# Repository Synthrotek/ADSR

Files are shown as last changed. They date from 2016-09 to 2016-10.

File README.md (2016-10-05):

# ADSR

##Important Information

The ADSR is Open Hardware, all hardware and software design in that project is Creative Commons licensed by Steve Harmon: CC-BY-SA: Attribution / ShareAlike.

##Information for re-use, adaptations or derivative works

Synthrotek is trademarked, and should not be used on any of works you create from these files.

We ask that if you want to re-use all or part of the files provided on github that you change the name of the product to something else, and remove any Synthrotek logos or names. Please do not contact Synthrotek for any support on the derivitive works. We can not be held liable for any derivitive works.

##About the ADSR

The Synthrotek ADSR is a small and simple envelope generator with some very useful features.  CV is additive for overall length of ADR stages in ADSR mode and add even more length to just the Release stage by adding CV into the Release jack. AR mode allows for snappy to long dynamic rhythm lengths. Very short minimum lengths, self cycling and a maximum output of 5 volts makes this tiny (4HP) envelope a very feature packed and versatile module.

Stage Lengths:
Attack: 4ms-2 seconds (up to ~ 4 seconds with CV)
Decay: 4ms-2 seconds (up to ~ 4 seconds with CV)
Sustain (based on gate length)
Release 4ms-2 seconds (up to ~ 4 seconds with CV)

Depth: 40mm
HP: 4
Current Draw: +12: 30mA, -12: n/a, +5: n/a

The source code was compiled using atmel studio 6.1

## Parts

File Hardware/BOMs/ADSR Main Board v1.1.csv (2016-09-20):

RefDes | Name | Value | Quantity | Vendor | Vendor Part No.
C1 | Cap Ceramic Radial - 18pF | 18pF | 1 | Mouser | 581-SR152A180JAA
C2 | Cap Ceramic Radial - 18pF | 18pF | 1 | Mouser | 581-SR152A180JAA
C3 | Cap Electrolytic Radial - 22uF | 22uF 25V | 1 | Mouser | 647-UVZ1E220MDD1TD 647-UVZ1E220MDD1TD 647-UVZ1E220MDD1TD
C4 | Cap Ceramic Radial - .1uF | .1uF | 1 | Mouser | 80-C316C104M5UCA7301
C5 | Cap Ceramic Radial - .1uF | .1uF | 1 | Mouser | 80-C316C104M5UCA7301
D1 | BAT85 |  | 1
D2 | BAT85 |  | 1
D3 | BAT85 |  | 1
D4 | BAT85 |  | 1
D5 | BAT85 |  | 1
D6 | BAT85 |  | 1
D7 | BAT85 |  | 1
P1 | Header RA - 10P (2x5) Protruding Left |  | 1 | Mouser | 538-10-89-4102
P2 | Header RA - 10P (2x5) Protruding Left |  | 1 | Mouser | 538-10-89-4102
P4 | Header 4-Wall - 10 Pin |  | 1 | Mouser | 517-30310-6002
R1 | Resistor - 1/4 Watt | 2K | 1
R2 | Resistor - 1/4 Watt | 1K | 1
R3 | Resistor - 1/4 Watt | 100K | 1
R4 | Resistor - 1/4 Watt | 100K | 1
R5 | Resistor - 1/4 Watt | 20K | 1
R6 | Resistor - 1/4 Watt | 1K | 1
R7 | Resistor - 1/4 Watt | 2K | 1
R8 | Resistor - 1/4 Watt | 1K | 1
R9 | Resistor - 1/4 Watt | 2K | 1
R10 | Resistor - 1/4 Watt | 100K | 1
R11 | Resistor - 1/4 Watt | 1R0 | 1
R12 | Resistor - 1/4 Watt | 2K | 1
R13 | Resistor - 1/4 Watt | 1K | 1
R14 | Resistor - 1/4 Watt | 1K | 1
U1 | ATMEGA48_PDIP |  | 1 | Mouser | 556-ATMEGA88A-PU
U2 | 74LS14N |  | 1
U3 | MCP4921 | DAC | 1 | Mouser | 579-MCP4921-E/P
VR1 | 78L05 |  | 1 | Mouser | 512-MC78L05ACP
X1 | Crystal - 20MHZ | 20MHZ | 1 | Mouser | 815-ABL-20-B2

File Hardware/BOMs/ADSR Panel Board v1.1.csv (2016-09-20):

# | RefDes | Name | Value | Quantity | Vendor | Vendor Part No.
1 | J1 | 3.5mm Jack WQP-PJ301M-12 2HP |  | 1 | WQP | WQP-PJ301M-12
2 | J2 | 3.5mm Jack WQP-PJ301M-12 2HP |  | 1 | WQP | WQP-PJ301M-12
3 | J3 | 3.5mm Jack WQP-PJ301M-12 2HP |  | 1 | WQP | WQP-PJ301M-12
4 | J4 | 3.5mm Jack WQP-PJ301M-12 2HP |  | 1 | WQP | WQP-PJ301M-12
7 | R1 | Bourns Lighted Slide Pot PTL Series | 10k | 1 | Mouser | 652-PTL20-10O0-103B2
8 | R2 | Bourns Lighted Slide Pot PTL Series | 10k | 1 | Mouser | 652-PTL20-10O0-103B2
9 | R3 | Bourns Lighted Slide Pot PTL Series | 10k | 1 | Mouser | 652-PTL20-10O0-103B2
10 | R4 | Bourns Lighted Slide Pot PTL Series | 10k | 1 | Mouser | 652-PTL20-10O0-103B2
11 | SW1 | LED-Switch SM102 ON-ON |  | 1 | LED-Switch | SM103
12 | SW2 | LED-Switch SM102 ON-ON |  | 1 | LED-Switch | SM103

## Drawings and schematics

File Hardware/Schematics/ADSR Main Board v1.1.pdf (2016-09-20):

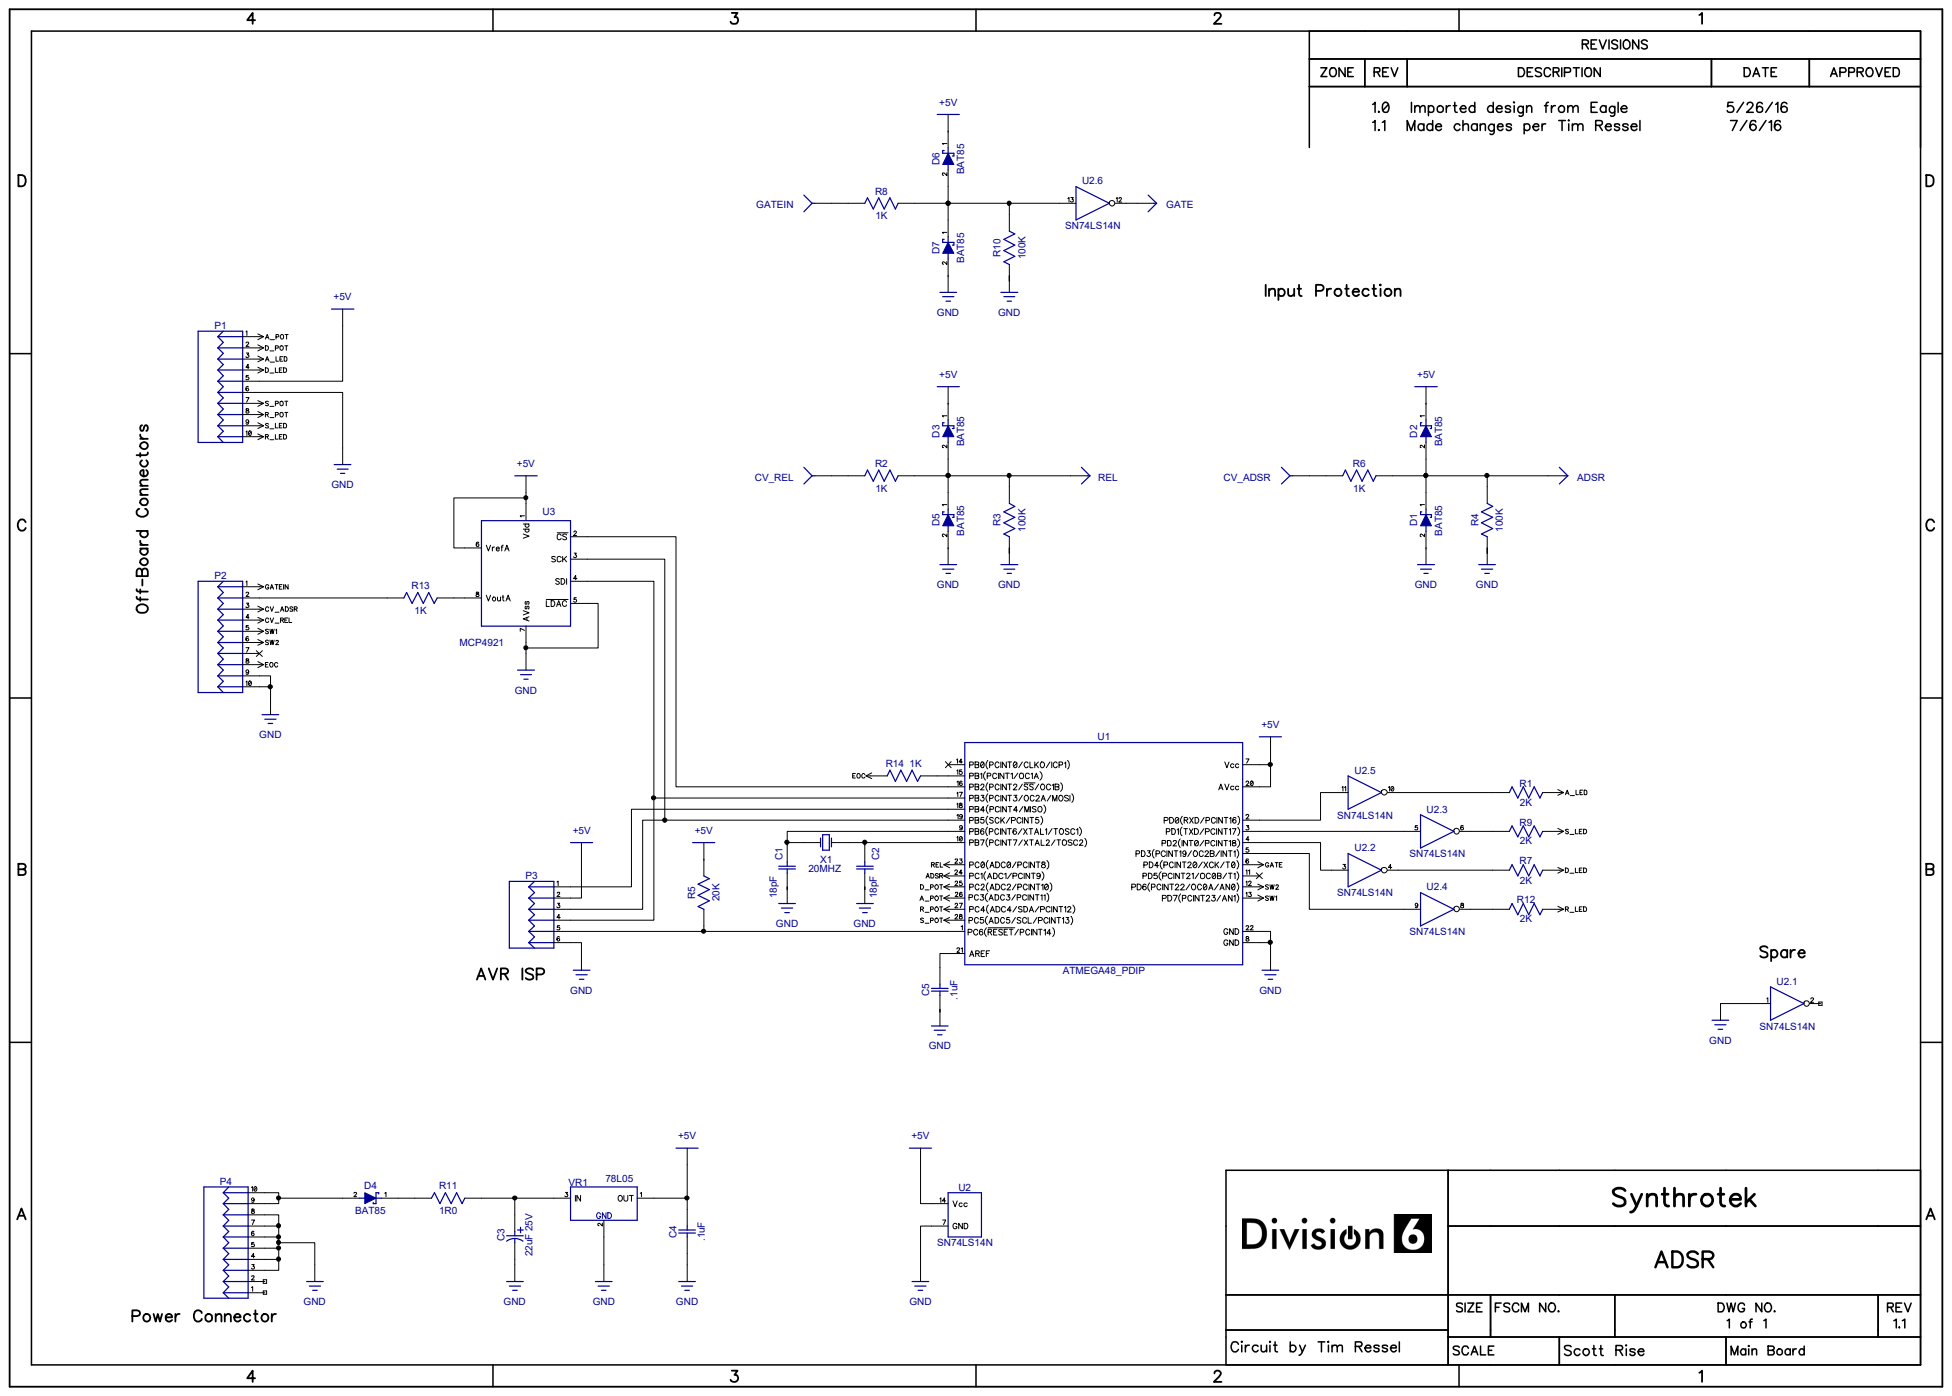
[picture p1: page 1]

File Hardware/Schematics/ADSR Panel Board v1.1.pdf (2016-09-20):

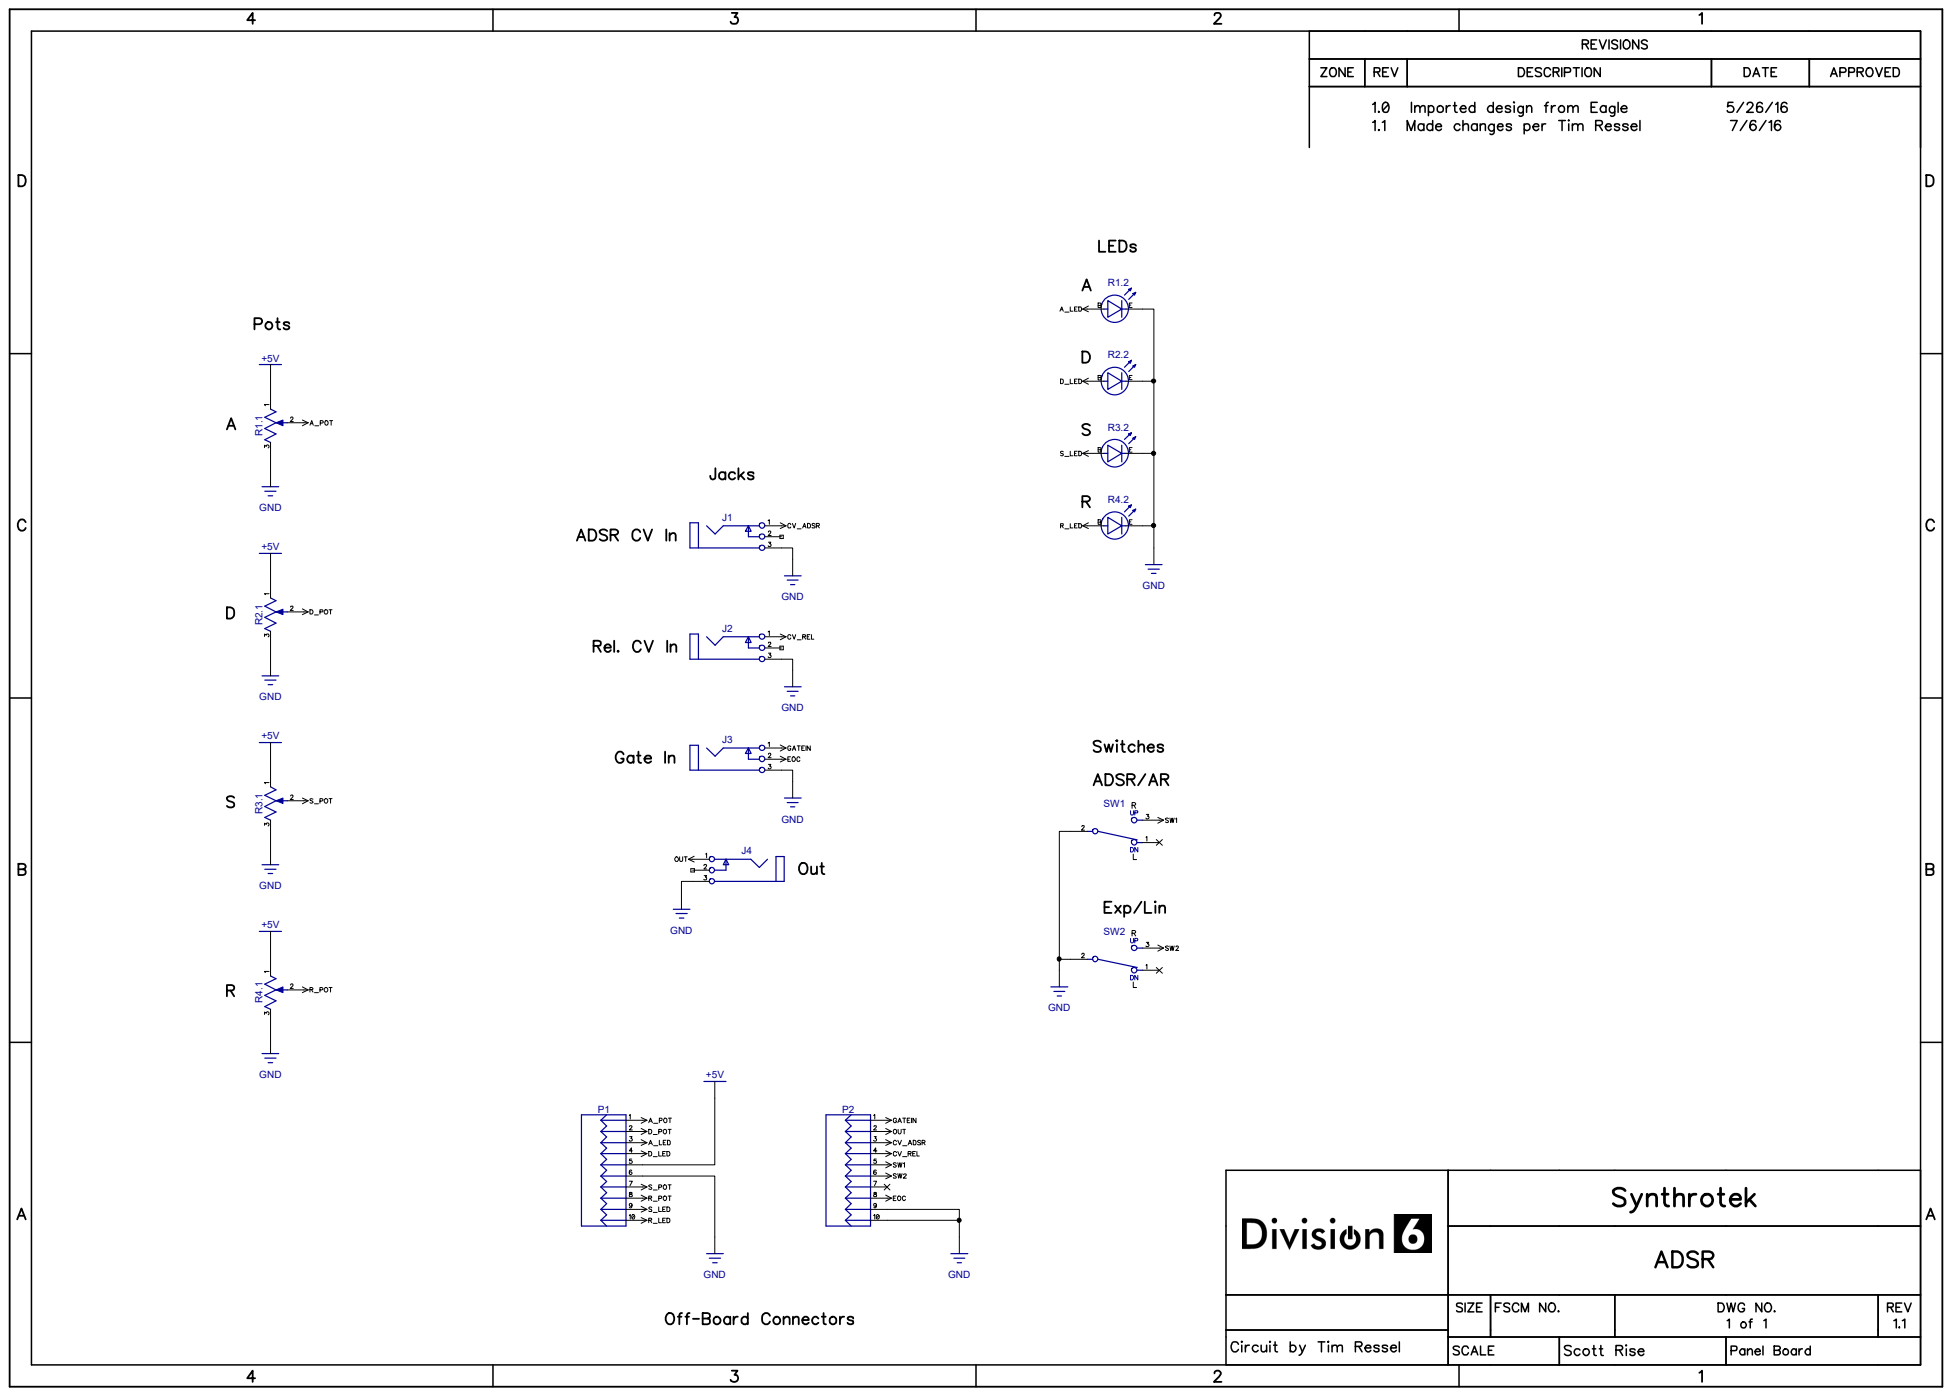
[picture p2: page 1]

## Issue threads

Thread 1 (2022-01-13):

eagle / cad files availability?

KeLaiFu, 2022-01-13:
I'f like to build this module but at the moment the slider used isnt available in my country and I would need to import it. Would it be possible to get the eagle / kicad file so I could switch the footprint for something more accessable?

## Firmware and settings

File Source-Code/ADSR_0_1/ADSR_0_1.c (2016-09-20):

/*
* ADSR_0_1.c
*
* Created: 6/28/2016 1:45:45 PM
*  Author: TimR
*/

#include "stdio.h"
#include "stdlib.h"
#include "string.h"
#include "avr/io.h"
#include "avr/interrupt.h"

// Prototypes
void process_adsr(void);
void	init_ports(void);
void	init_devices(void);
void	pgm_init(void);
void	timer_init(void);
void SendToShiftyTypes(void);


// Hardware Defines
#define LEDS_ATTACK		0x01
#define LEDS_DECAY		0x04
#define LEDS_SUSTAIN	0x02
#define LEDS_RELEASE	0x08
#define LEDS_IDLE_MASK	0xF0

#define SW_AR		PIND&0x80		// 0=AR, 1=ADSR
#define SW_LIN		PIND&0x40		// 0=lin, 1=expo

#define	EOC_HI		PORTB|=0x02;
#define	EOC_LO		PORTB&=~0x02;

// Shifty Types
#define	SS_LO		PORTB&=~0x04;
#define	SS_HI		PORTB|=0x04;

// LED macros
#define LED_ATTACK	{PORTD|=~LEDS_IDLE_MASK;PORTD&=~LEDS_ATTACK;}
#define LED_DECAY	{PORTD|=~LEDS_IDLE_MASK;PORTD&=~LEDS_DECAY;}
#define LED_SUSTAIN	{PORTD|=~LEDS_IDLE_MASK;PORTD&=~LEDS_SUSTAIN;}
#define LED_RELEASE	{PORTD|=~LEDS_IDLE_MASK;PORTD&=~LEDS_RELEASE;}
#define LED_IDLE	{PORTD|=~LEDS_IDLE_MASK;}

//#define	EXPOEPSILON		0x01FFFFFF
#define	EXPOEPSILON		0x0000FFFF
#define ADCCHANNELMAX	6
#define	EOC_TIMEOUT		9			// about ?mS

// Globals

enum states {
	s_idle,
	s_att,
	s_dec,
	s_sus,
	s_rel
};

struct adsr {
	uint32_t	attack;
	uint32_t	decay;
	uint32_t	sustain;
	uint32_t	release;
	uint32_t	accum;
	uint32_t	curDac;
	uint8_t		state;
};
volatile struct adsr thisADSR;

volatile	uint16_t	rawAdcPots[4];	// raw pot values from ADC
volatile	uint16_t	rawAdcSum[4];	// sum of raw pot values and adsr/rel values
uint16_t	rel_cv,adsr_cv;				// raw ADC values from rel and adsr jacks
uint8_t		flgShape;					//sets lin or expo shape, 
uint8_t		flgAR,flgARold;				//sets AR mode -- from FP switch
volatile uint8_t	flgGate;			// set when a rising Gate is detected
uint8_t		thisAdcChannel;				// current ADC mux setting
uint8_t		flgProcess;					// shows its time to process the ADSR
volatile uint8_t		flgEOC,tmrEOC;

int main(void)
{
	cli();
	init_ports();
	init_devices();
	timer_init();
	pgm_init();
	sei();
	
	ADCSRA |= (1<<ADIE);					// enable ADC interrupts
	ADCSRA |= (1<<ADSC);				//start next conversion

	while(1)
	{
		// wait for gate flag
		if(flgGate)
		{
			flgGate=0;			// clear flag
			LED_ATTACK
			thisADSR.state = s_att;
		}
		// wait for processing flag
		// decouples from the irq so the processing does not happen
		// inside an irq.
		if(flgProcess)
		{
			flgProcess=0;			// clear flag
			// set env based on switch
			if(SW_AR)
				flgAR=0;		// adsr
			else
				flgAR=1;		//ar
			if(flgARold!=flgAR)
				thisADSR.state = s_att;
			flgARold=flgAR;
			
			// set shape based on switch
			if(SW_LIN)
				flgShape=0;		// expo
			else
				flgShape=1;		// lin			
			process_adsr();
			SendToShiftyTypes();
		}
	}
}


void	init_ports(void)
{
	DDRB = 0x2E;
	DDRC = 0x00;		// all inputs of the ADC variety
	PORTD = 0xC0;		// pull ups on PD6 & 7
	DDRD = 0x0F;		//PD0-3 outputs, rest inputs
}


void process_adsr(void)
{
	static uint32_t		NextExpoAmt;
	//	static uint8_t		flgRetrigOld;
	//	uint16_t			index;
	cli();
	
	switch (thisADSR.state) {
		case s_idle:
		break;
		
		case s_att:
		if(flgShape) {
			//linear processing
			if((int64_t)(0x7fffffff-(thisADSR.accum)) < (thisADSR.attack)) {
				thisADSR.accum=0x7fffffff;
				if(flgAR) {
					thisADSR.state=s_rel;
					LED_RELEASE
				} else {
					thisADSR.state=s_dec;
					LED_DECAY
				}
			}
			else
			thisADSR.accum+=((thisADSR.attack)/2);
			thisADSR.curDac=thisADSR.accum*2;
		}
		else {
			//expo processing
			NextExpoAmt=(0x9fffffff-thisADSR.accum);
			NextExpoAmt=NextExpoAmt/((rawAdcSum[0]*2)+8);
			NextExpoAmt=NextExpoAmt*3;
			NextExpoAmt=NextExpoAmt/4;
			
			if(NextExpoAmt>0x7ffffff0)
			NextExpoAmt=0x7ffffff0;
			if(NextExpoAmt<0)
			NextExpoAmt=0x7ffffff0;
			if((0x7fffffff-(thisADSR.accum)) <= NextExpoAmt+EXPOEPSILON) {
				thisADSR.accum=0x7fffffff;
				if(flgAR) {
					thisADSR.state=s_rel;
					LED_RELEASE
					} else {
					thisADSR.state=s_dec;
					LED_DECAY
				}
			}
			else
			thisADSR.accum+=NextExpoAmt;
			thisADSR.curDac=thisADSR.accum*2;
		}
		
		break;
		
		case s_dec:
		if(flgShape) {
			//linear processing
			if(((int64_t)thisADSR.accum - (int64_t)(thisADSR.decay)) < thisADSR.sustain/2) {
				thisADSR.accum=thisADSR.sustain/2;
				thisADSR.state=s_sus;
				LED_SUSTAIN
			}
			else
			thisADSR.accum-=(thisADSR.decay/2);
			
			thisADSR.curDac=thisADSR.accum*2;
			//break;
			
			} else {
			//expo processing
			NextExpoAmt=(thisADSR.accum-(thisADSR.sustain/2));
			NextExpoAmt=NextExpoAmt/((rawAdcSum[1]*3)+12);
			NextExpoAmt=((NextExpoAmt*12)/10);
			NextExpoAmt=NextExpoAmt;

			if((int64_t)thisADSR.accum-((thisADSR.sustain/2)+EXPOEPSILON)<NextExpoAmt) {
				thisADSR.accum-=NextExpoAmt*2;
				thisADSR.state=s_sus;
				LED_SUSTAIN
			}
			else
			thisADSR.accum-=NextExpoAmt*2;
			thisADSR.curDac=thisADSR.accum*2;
		}

		break;
		
		case s_sus:
		thisADSR.accum=thisADSR.sustain/2;
		thisADSR.curDac=thisADSR.accum*2;
		//if(PORTA.IN & PIN6_bm)
		if((PIND & 0x10)==0x10)	{					// is Gate went away i.e. high (inverted)
			thisADSR.state=s_rel;						// jump to release state
			LED_RELEASE
		}
		break;

		case s_rel:
		if(flgShape) {
			//linear processing
			if(thisADSR.accum <= (thisADSR.release)) {
				thisADSR.accum=0;
				thisADSR.state=s_idle;
				LED_IDLE
				
				// use for cycle mode...
				EOC_HI;
				tmrEOC=0;
				flgEOC=1;
				
			}
			else
			thisADSR.accum-=((thisADSR.release)/2);
			
			//process exp curve crap
			thisADSR.curDac=thisADSR.accum*2;
			} else {
			//process exp curve
			NextExpoAmt=thisADSR.accum;
			NextExpoAmt=NextExpoAmt/((rawAdcSum[3]*3)+12);
			NextExpoAmt=((NextExpoAmt*3)/2);
			NextExpoAmt=NextExpoAmt;

			//if(thisADSR.accum <= EXPOEPSILON) {
			if((int32_t)thisADSR.accum<(NextExpoAmt+EXPOEPSILON)) {
				thisADSR.accum=0;
				thisADSR.state=s_idle;
				LED_IDLE
				// use for cycle mode...
				EOC_HI;
				tmrEOC=0;
				flgEOC=1;

			}
			
			else
			thisADSR.accum-=((NextExpoAmt/8)*18);
			thisADSR.curDac=thisADSR.accum*2;
			break;
		}
	}
	sei();
}


void init_devices(void)
{
	//
	// sets up ADC system
	//
	ADMUX = (1<<REFS0);		//AVCC as reference
	ADCSRA = (1<<ADPS2)|(1<<ADPS1)|(1<<ADPS0)|(1<<ADEN);

	//
	// enable IRQ on Gate jack input
	PCMSK2 = (1<<PCINT20);		
	PCICR = (1<<PCIE2);						//enable interrupts
	
	// ***SPI***
	SPCR = (1<<SPE)|(1<<MSTR)|(1<<SPR0);	// SPI enable	
}


void pgm_init(void)
{
	// setup mux channel
	thisAdcChannel=0;
	ADMUX |= thisAdcChannel;
	LED_IDLE
	SS_HI;
}


void adcProcess(void)
{
	rawAdcSum[0]=rawAdcPots[0]+adsr_cv;
	rawAdcSum[1]=rawAdcPots[1]+adsr_cv;
	rawAdcSum[2]=rawAdcPots[2];
	rawAdcSum[3]=rawAdcPots[3]+adsr_cv+rel_cv;
	
	thisADSR.attack=0x20000000/((rawAdcSum[0]+0x02)/0x02);
	thisADSR.decay=0x20000000/((rawAdcSum[1]+0x02)/0x02);
	thisADSR.sustain=(uint32_t)rawAdcSum[2]<<22;
	thisADSR.release=0x20000000/((rawAdcSum[3]+0x02)/0x02);
}


void SendToShiftyTypes(void)
{
	uint8_t		dummy;
	uint16_t	sendVal;

	cli();
	SS_LO;
	
	sendVal = thisADSR.curDac>>20;
	sendVal = sendVal | 0x3000;			//gain=1,active mode
	
	SPDR=sendVal>>8;					// send MSB
	do {} while (!(SPSR&(1<<SPIF)));
	dummy=SPDR; 				//dummy read to clear flag

	SPDR=sendVal&0x00FF;				// send LSB
	do {} while (!(SPSR&(1<<SPIF)));
	dummy=SPDR; 				//dummy read to clear flag
	
	SS_HI;
	sei();
}

void timer_init(void)
{
	// for 20.0000MHz clock
	// timer 0 is the 1mS (0.5mS?) tick
	TCCR0A  = (1<<WGM01);					// ctc mode
	TCCR0B  = (1<<CS02); 					// divide by 256
	OCR0A   = 0x26;							// or 38 decimal -- 0.5mS
	TIMSK0	= 1<<OCIE0A;					// output compare A match irq
}


//	ADC interrupt
ISR(ADC_vect)
{
	//process results
	switch (thisAdcChannel) {
		case 0:
		rel_cv = ADC;
		break;
		case 1:
		adsr_cv = ADC;
		break;
		case 2:
		rawAdcPots[1] = ADC;
		break;
		case 3:
		rawAdcPots[0] = ADC;
		break;
		case 4:
		rawAdcPots[3] = ADC;
		break;
		case 5:
		rawAdcPots[2] = ADC;
		break;
		
	}
	// do the math
	adcProcess();
	//set up for next channel
	thisAdcChannel+=1;
	if(thisAdcChannel >= ADCCHANNELMAX)
	thisAdcChannel=0;
	ADMUX &= 0xF0;
	ADMUX |= thisAdcChannel;
	ADCSRA |= (1<<ADSC);				//start next conversion
}


ISR (TIMER0_COMPA_vect)
{
	// end of cycle timer
	// terminates pulse began at end of release
	// width ~10mS
	if(flgEOC){
		tmrEOC++;
		if(tmrEOC>=EOC_TIMEOUT) {
			EOC_LO;
			flgEOC=0;
		}
	}

	flgProcess=1;
}


ISR(PCINT2_vect)
{
	static uint8_t	pinDmem=0x02;
	uint8_t	pinDstate;
	
	// processes Gate interrupt
	// uses pinDmem to remember old state to check for change
	// and to detect falling edge (Gate is inverted in hardware)
	
	pinDstate=PIND;					//get the state of PIND once	
	if((pinDstate&0x10)!=(pinDmem&0x10)) {		//did it change?
		if((pinDstate&0x10)==0x00)	{			//is it our edge?
			flgGate=1;
		}
	}
	
	pinDmem=pinDstate;					//remember this port sample
}
